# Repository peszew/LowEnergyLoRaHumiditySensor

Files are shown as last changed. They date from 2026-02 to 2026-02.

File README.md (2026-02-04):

# LoRa Wireless Humidity Sensor





> **Bachelor Thesis Project** - A complete IoT solution for wireless environmental monitoring using LoRa communication, featuring a custom-designed PCB with ultra-low power consumption.

**Author:** Piotr Szewczyk  
**University:** Warsaw University of Technology  
**Year:** 2025

---

## Table of Contents

- [Overview](#overview)
- [Features](#features)
- [System Architecture](#system-architecture)
- [Hardware](#hardware)
- [Software](#software)
- [Project Structure](#project-structure)
- [Getting Started](#getting-started)
- [Configuration](#configuration)
- [Power Consumption](#power-consumption)
- [Documentation](#documentation)
- [License](#license)

---

## Overview

This project implements a **wireless humidity and temperature monitoring system** using **LoRa (Long Range)** technology. The system consists of:

1. **Sensor Node** - A battery-powered, custom PCB device that measures environmental conditions and transmits data wirelessly
2. **Gateway/Receiver** - A Raspberry Pi-based receiver that collects data and publishes it to an MQTT broker for integration with home automation systems

The sensor is designed for **ultra-low power consumption**, making it ideal for remote monitoring applications in agriculture, warehouses, smart homes, and industrial environments.

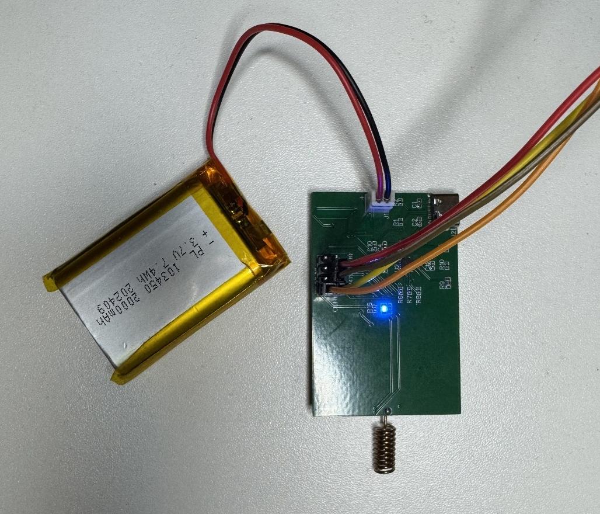
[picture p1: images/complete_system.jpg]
Complete System


---

## Features

| Feature | Description |
|---|---|
| **Temperature Monitoring** | High-precision measurement with HDC1080 sensor (±0.2°C accuracy) |
| **Humidity Monitoring** | Accurate humidity readings (±2% RH accuracy) |
| **Long-Range Communication** | LoRa 868 MHz with RFM95 module (up to several km range) |
| **Battery Monitoring** | Integrated BQ27411 fuel gauge for accurate battery level reporting |
| **Ultra-Low Power** | STM32L0 low-power modes for extended battery life |
| **Smart Alerts** | Automatic alerts for low battery (<20%) or high humidity (>70%) |
| **MQTT Integration** | Seamless integration with home automation systems (Home Assistant, etc.) |
| **Custom PCB Design** | Professionally designed 2-layer PCB with all manufacturing files included |

---

## System Architecture

```
┌─────────────────────────────────────────────────────────────────────────────┐
│                           SENSOR NODE (Battery Powered)                     │
│  ┌──────────────┐   ┌──────────────┐   ┌──────────────┐   ┌──────────────┐  │
│  │   HDC1080    │   │   BQ27411    │   │  STM32L071   │   │    RFM95     │  │
│  │  Temp/Hum    │──▶│  Fuel Gauge  │──▶│     MCU      │──▶│   LoRa TX    │  │
│  │   Sensor     │   │   (I2C)      │   │  (I2C/SPI)   │   │   868 MHz    │  │
│  └──────────────┘   └──────────────┘   └──────────────┘   └──────┬───────┘  │
└──────────────────────────────────────────────────────────────────┼──────────┘
                                                                   │ LoRa
                                                                   ▼
┌─────────────────────────────────────────────────────────────────────────────┐
│                          GATEWAY (Raspberry Pi)                             │
│  ┌──────────────┐   ┌──────────────┐   ┌──────────────┐   ┌──────────────┐  │
│  │    RFM95     │   │   Python     │   │    MQTT      │   │    Home      │  │
│  │   LoRa RX    │──▶│   Receiver   │──▶│   Broker     │──▶│  Automation  │  │
│  │   868 MHz    │   │   Script     │   │ (Mosquitto)  │   │              │  │
│  └──────────────┘   └──────────────┘   └──────────────┘   └──────────────┘  │
└─────────────────────────────────────────────────────────────────────────────┘
```

---

## Hardware

### Assembled PCB

| Sensor Node PCB | With Battery Connected |
|:---:|:---:|
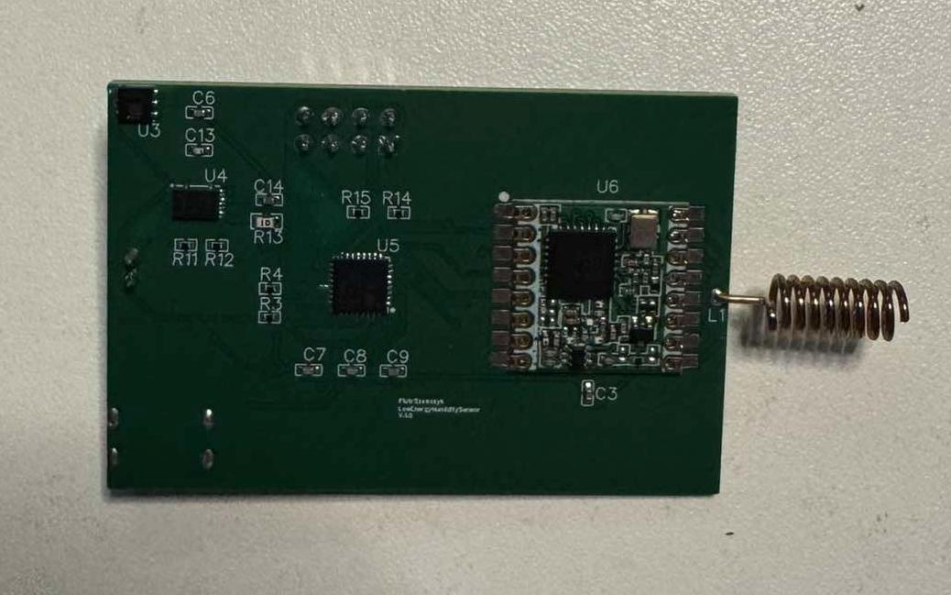
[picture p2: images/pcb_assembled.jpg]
PCB Assembled
|  | Complete System |

### Gateway (Raspberry Pi)

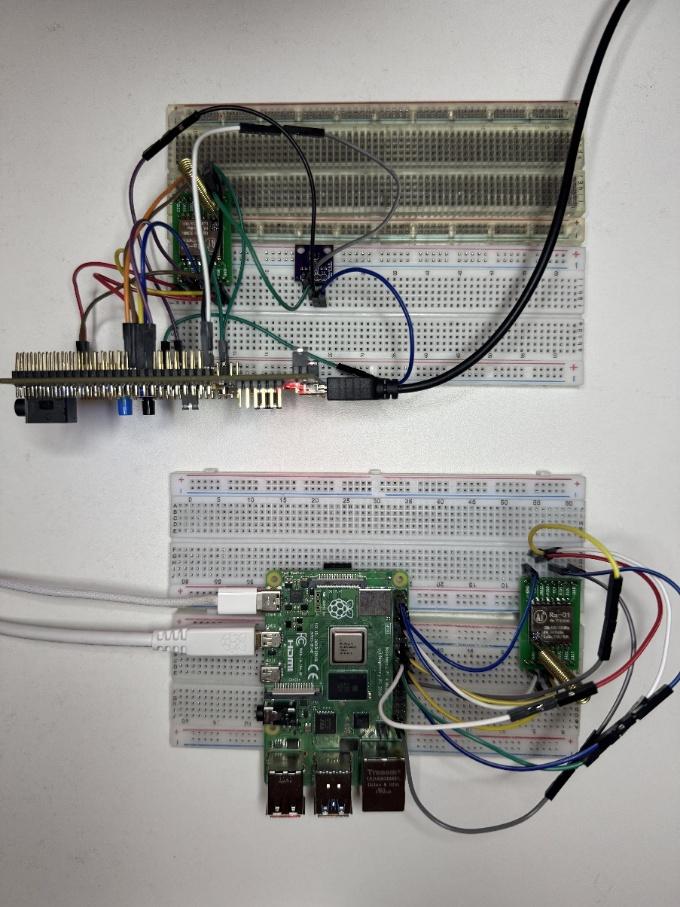
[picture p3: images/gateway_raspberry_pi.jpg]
Raspberry Pi Gateway


### Schematic

The complete schematic includes four main sections:

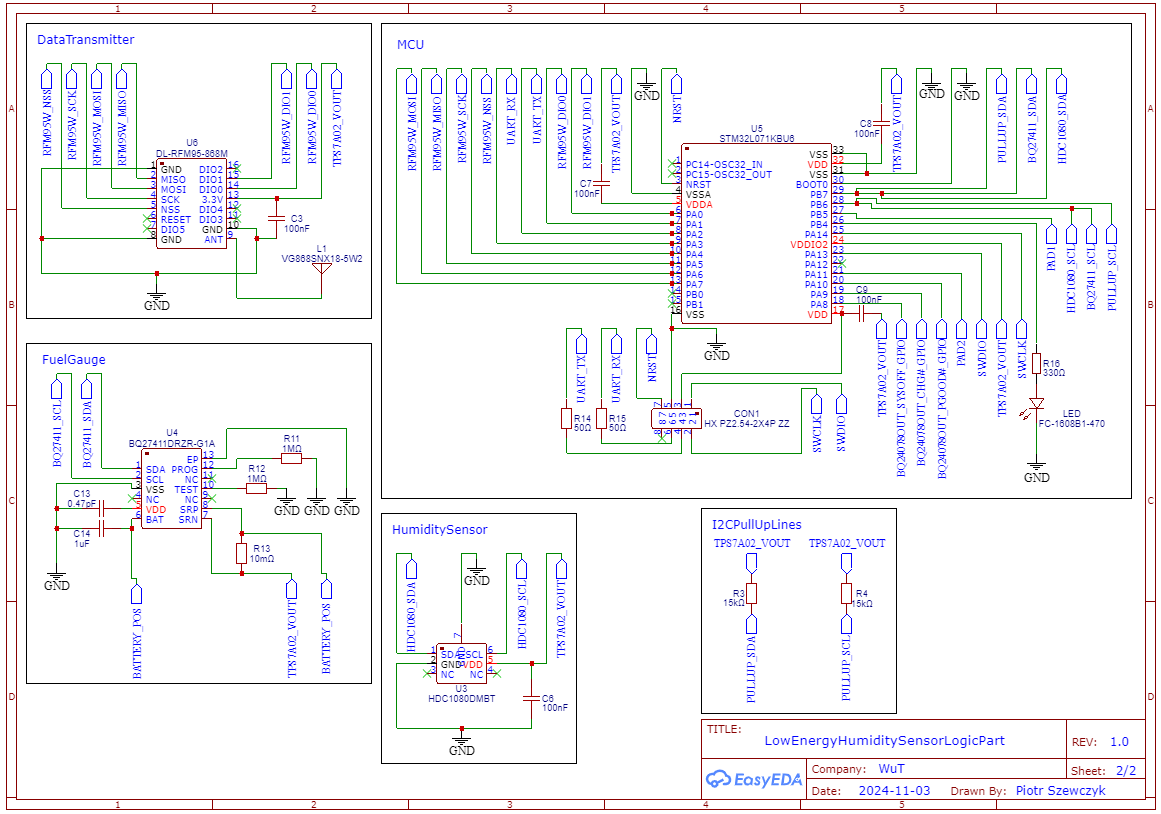
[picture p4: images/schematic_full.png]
Full Schematic


| Power Management | MCU Section |
|:---:|:---:|
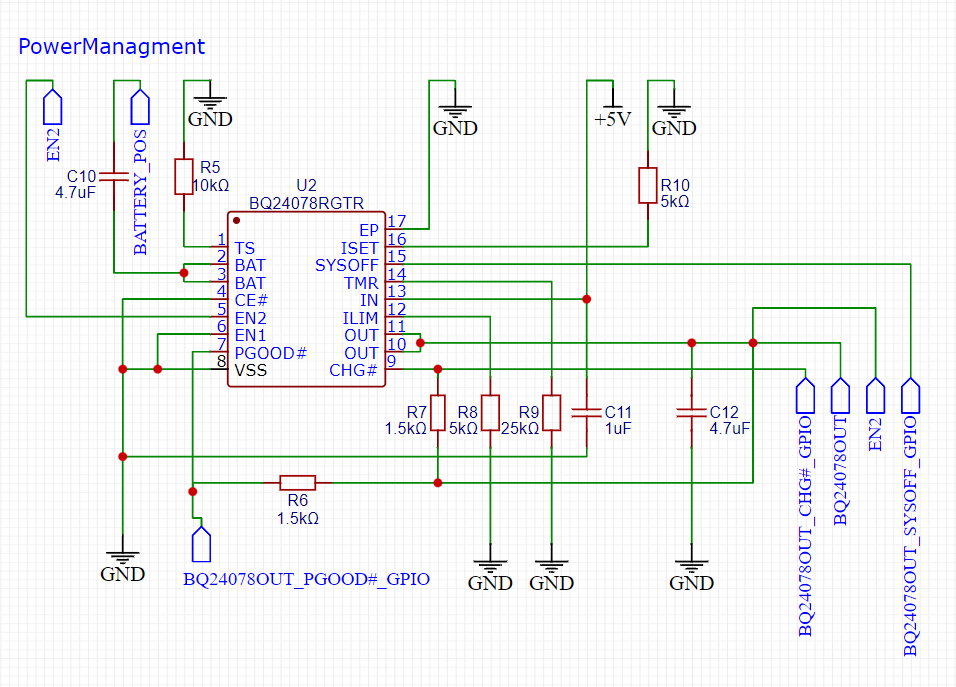
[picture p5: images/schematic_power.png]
Power Schematic
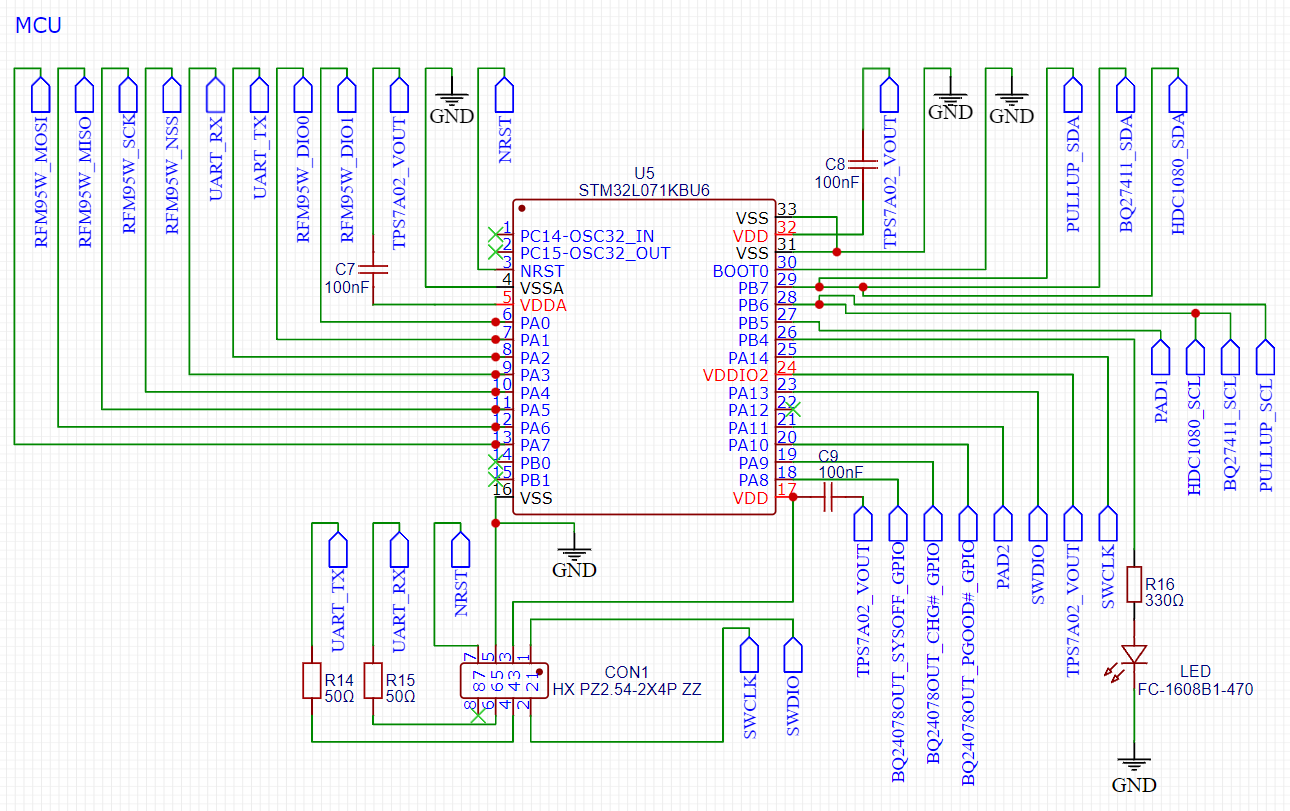
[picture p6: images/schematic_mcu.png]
MCU Schematic
|  |  |

| Fuel Gauge & LoRa | Humidity Sensor |
|:---:|:---:|
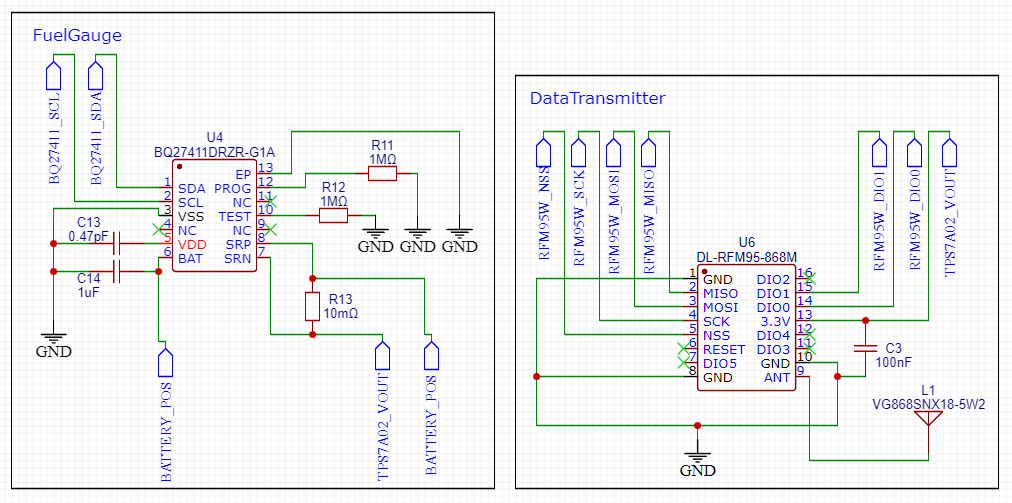
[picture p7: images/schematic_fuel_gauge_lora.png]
Fuel Gauge & LoRa
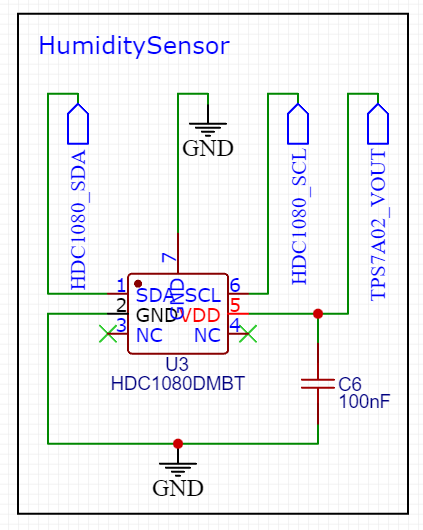
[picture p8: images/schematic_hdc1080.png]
HDC1080 Schematic
|  |  |

### PCB Layout

| Power Section | Main Section |
|:---:|:---:|
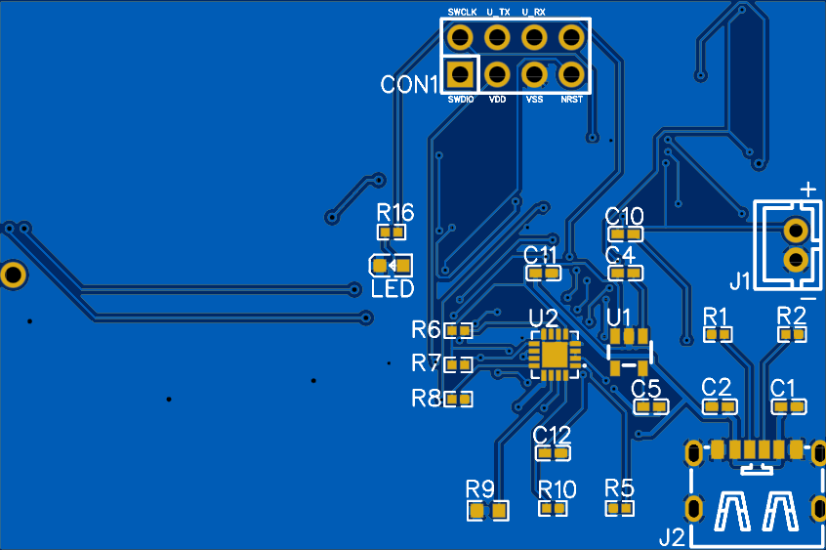
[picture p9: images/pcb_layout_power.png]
PCB Layout Power
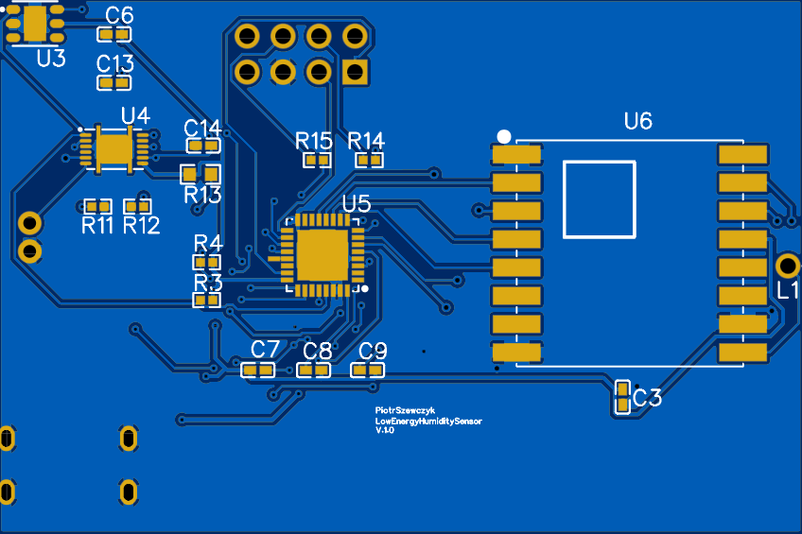
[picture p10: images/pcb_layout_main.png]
PCB Layout Main
|  |  |

### Main Components

| Component | Part Number | Function | Interface |
|---|---|---|---|
| **Microcontroller** | STM32L071KBU6 | Ultra-low-power ARM Cortex-M0+ | - |
| **Humidity/Temperature Sensor** | HDC1080DMBT | Environmental sensing | I2C |
| **LoRa Module** | DL-RFM95-868M | Wireless communication | SPI |
| **Battery Fuel Gauge** | BQ27411DRZR-G1A | Battery level monitoring | I2C |
| **LDO Voltage Regulator** | TPS7A0233PDBVR | 3.3V power supply | - |
| **Battery Charger** | BQ24078RGTR | Li-Ion/Li-Po charging via USB-C | - |
| **Antenna** | VG868SNX18-5W2 | 868 MHz helical antenna | - |

### PCB Details

- **Layers:** 2-layer PCB
- **Dimensions:** Compact design for portable applications
- **Connectors:** 
  - USB Type-C for charging
  - JST PH 2.54mm for battery connection
  - 2x4 pin header for programming/debugging

### Manufacturing Files

The `załączniki/` directory contains all files needed for PCB manufacturing:

- `Gerber_HumSensorV1.0_PCB_HumSensorV1.0_2025-01-28/` - Gerber files for PCB fabrication
- `BOM_HumSensorV1.0_2025-01-28.csv` - Bill of Materials with LCSC part numbers
- `PickAndPlace_PCB_HumSensorV1.0_2025-01-28.csv` - Pick and place file for SMT assembly

---

## Software

### Sensor Node Firmware (STM32)

The firmware is developed using **STM32CubeIDE** and the **STM32 HAL library**.

**Key Features:**
- Ultra-low power operation using STM32 STOP mode
- RTC-based wake-up for periodic measurements
- Averaged humidity readings for stable data
- LoRa transmission with error handling
- Automatic alert generation for critical conditions

**Driver Modules:**

| File | Description |
|---|---|
| `hdc1080.c/.h` | HDC1080 temperature/humidity sensor driver |
| `rfm95.c/.h` | RFM95 LoRa transceiver driver |
| `bq27411.c/.h` | BQ27411 battery fuel gauge driver |
| `main.c` | Main application logic |

### Gateway/Receiver (Python)

The receiver runs on a **Raspberry Pi** and communicates with the sensor via LoRa.

**Features:**
- Continuous LoRa message reception
- Data parsing and validation
- MQTT publishing for home automation integration

**MQTT Topics:**
```
home/lora/temperature  →  Temperature in °C
home/lora/humidity     →  Humidity in %
home/lora/battery      →  Battery level in %
```

---

## Project Structure

```
311105_inz/
├── README.md                          # This file
├── images/                            # Project photos and schematics
│   ├── pcb_assembled.jpg              # Assembled PCB
│   ├── complete_system.jpg            # Complete sensor with battery
│   ├── gateway_raspberry_pi.jpg       # Raspberry Pi gateway
│   ├── schematic_full.png             # Full schematic
│   ├── schematic_mcu.png              # MCU section schematic
│   ├── schematic_power.png            # Power management schematic
│   ├── pcb_layout_main.png            # PCB layout (main)
│   └── pcb_layout_power.png           # PCB layout (power)
├── załączniki/                        # Project attachments
│   ├── 311105_inz.pdf                 # Full thesis documentation (Polish)
│   │
│   ├── HumiditySensor/                # Main firmware project
│   │   └── HumiditySensor/
│   │       ├── Core/
│   │       │   ├── Inc/               # Header files
│   │       │   │   ├── hdc1080.h      # Temperature/humidity sensor
│   │       │   │   ├── rfm95.h        # LoRa transceiver
│   │       │   │   ├── bq27411.h      # Battery fuel gauge
│   │       │   │   └── main.h
│   │       │   └── Src/               # Source files
│   │       │       ├── hdc1080.c
│   │       │       ├── rfm95.c
│   │       │       ├── bq27411.c
│   │       │       └── main.c
│   │       ├── Drivers/               # STM32 HAL drivers
│   │       └── HumiditySensor.ioc     # STM32CubeMX configuration
│   │
│   ├── Gerber_HumSensorV1.0.../       # PCB Gerber files
│   ├── BOM_HumSensorV1.0_2025-01-28.csv        # Bill of Materials
│   ├── PickAndPlace_PCB_HumSensorV1.0_2025-01-28.csv  # SMT assembly file
│   │
│   ├── RFM95_receiver.py              # Full-featured LoRa receiver
│   ├── lora_receiver.py               # Simple LoRa receiver
│   │
│   ├── hdc1080testing.c               # HDC1080 test driver
│   ├── loratesting.c                  # LoRa test driver
│   │
│   ├── testingdht11/                  # DHT11 sensor testing (Arduino)
│   │   └── testingdht11.ino
│   └── testingsyh2r/                  # SYH-2R sensor testing (Arduino)
│       └── testingsyh2r.ino
```

---

## Getting Started

### Prerequisites

**For Sensor Node:**
- STM32CubeIDE (or any ARM GCC toolchain)
- ST-Link programmer/debugger
- USB Type-C cable for charging

**For Raspberry Pi Gateway:**
- Raspberry Pi (any model with SPI support)
- RFM95 LoRa module connected via SPI
- Python 3.x with required packages

### Building the Firmware

1. Clone this repository:
   ```bash
   git clone https://github.com/peszew/LowEnergyLoRaHumiditySensor.git
   ```

2. Open the project in STM32CubeIDE:
   ```
   File → Open Projects from File System → Select załączniki/HumiditySensor/HumiditySensor
   ```

3. Build and flash to the STM32L071:
   ```
   Project → Build All
   Run → Debug
   ```

### Setting Up the Receiver

1. Install Python dependencies:
   ```bash
   pip install spidev paho-mqtt
   ```

2. Enable SPI on Raspberry Pi:
   ```bash
   sudo raspi-config
   # Navigate to: Interfacing Options → SPI → Enable
   ```

3. Run the receiver script:
   ```bash
   python3 RFM95_receiver.py
   ```

---

## Configuration

### LoRa Parameters

| Parameter | Value | Description |
|---|---|---|
| Frequency | 868 MHz | EU ISM band (adjust for your region) |
| Bandwidth | 125 kHz | Standard LoRa bandwidth |
| Spreading Factor | SF7 | Balance between range and speed |
| Coding Rate | 4/5 | Error correction level |

To modify these, edit `rfm95.h`:

```c
#define DEFAULT_FREQUENCY 868000000  // Frequency in Hz
#define DEFAULT_BANDWIDTH 0x72       // 125 kHz
#define DEFAULT_SPREADING_FACTOR 0x74 // SF7
```

### Alert Thresholds

Configured in `main.c`:

```c
if (batteryLevel < 20.0 || humidity > 70.0) {
    // Send alert message
}
```

---

## Power Consumption

The system is optimized for battery operation:

| Mode | Current | Description |
|---|---|---|
| Active (Measuring + Transmitting) | ~50 mA | Brief periods during data transmission |
| STOP Mode (Sleep) | ~2 µA | Most of the operating time |

With a **2000 mAh battery** and measurements every hour, the expected battery life is **several months**.

---

## Documentation

The complete thesis documentation is available in:

**`załączniki/311105_inz.pdf`** (Polish language)

This includes:
- Detailed theoretical background
- System design decisions
- Hardware schematics
- Software implementation details
- Test results and measurements
- Conclusions and future work

---

## License

This project was created as a Bachelor Thesis at **Warsaw University of Technology**.

- The thesis and related materials are the intellectual property of Warsaw University of Technology
- Available for **educational and research purposes only**
- Commercial use requires permission from the author and university

See the [LICENSE](LICENSE) file for details.

---

## Acknowledgments

- STMicroelectronics for the STM32 HAL library
- Texas Instruments for HDC1080 and BQ27411 sensor datasheets
- Semtech for LoRa technology documentation
- Warsaw University of Technology

---

<p align="center">
  <i>Bachelor Thesis Project</i><br>
  <b>Piotr Szewczyk</b><br>
  Warsaw University of Technology, 2025
</p>

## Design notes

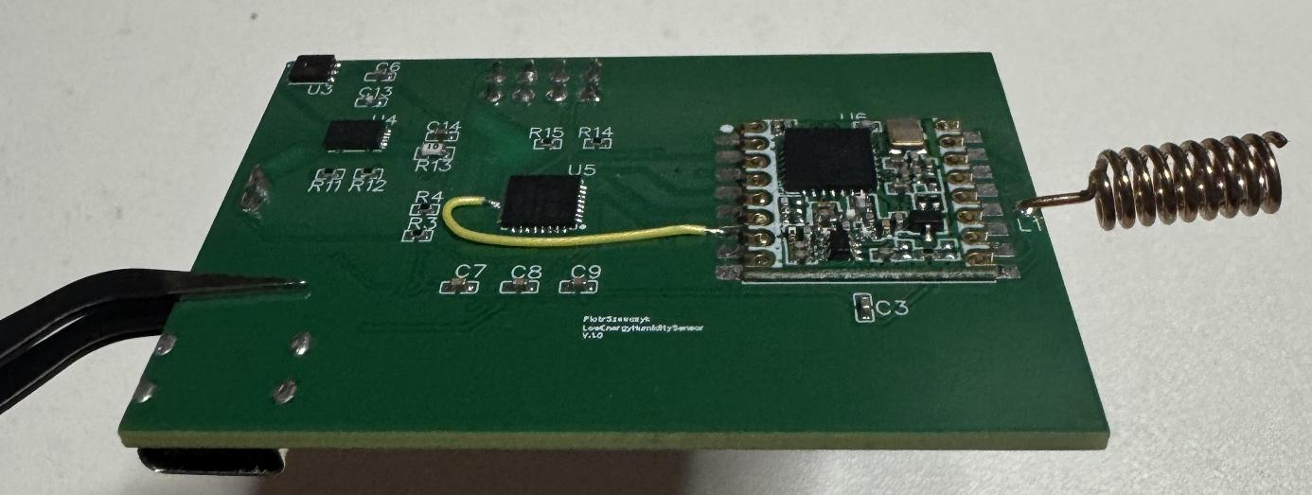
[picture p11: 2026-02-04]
images/pcb_with_wire.jpg

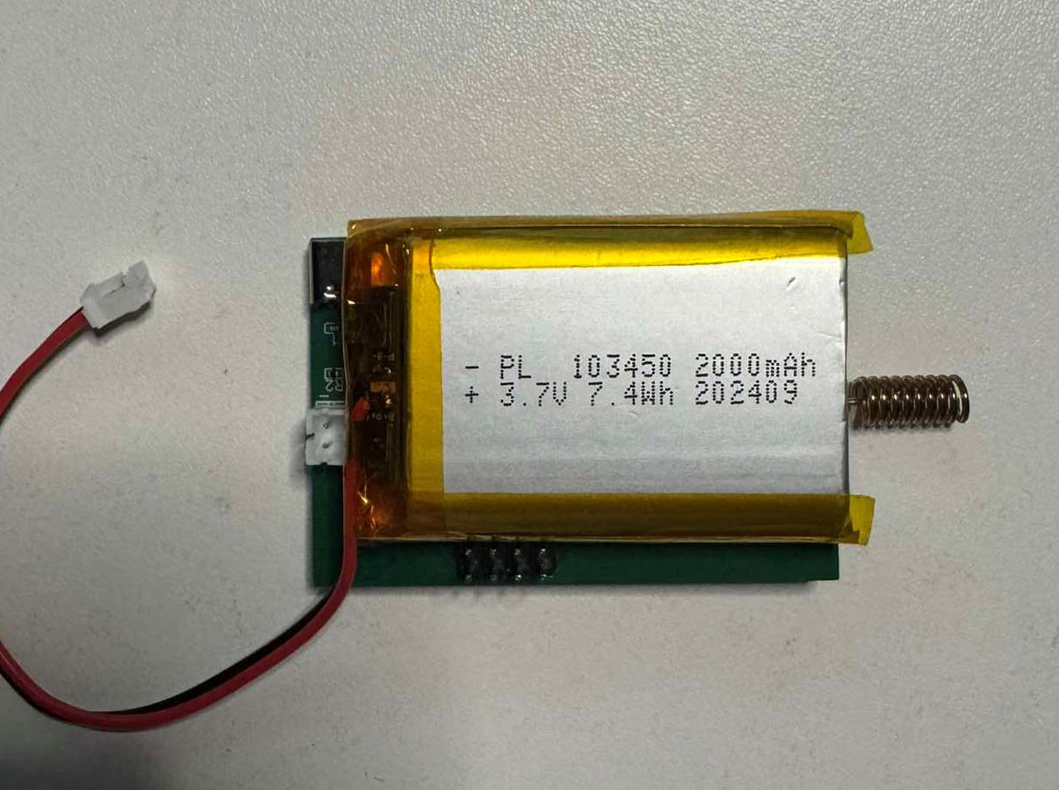
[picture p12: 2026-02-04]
images/battery_module.jpg

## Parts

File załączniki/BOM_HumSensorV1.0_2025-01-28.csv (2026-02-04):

ID | Name | Designator | Footprint | Quantity | Manufacturer Part | Manufacturer | Supplier | Supplier Part | Price
1 | FC-1608B1-470 | LED | LED0603-RD | 1 | FC-1608B1-470 | 国星光电 | LCSC | C19189746 | 0.008
2 | BQ24078RGTR | U2 | VQFN-16_L3.0-W3.0-P0.50-BL-EP | 1 | BQ24078RGTR | TI(德州仪器) | LCSC | C473396 | 1.261
3 | 330Ω | R16 | R0402 | 1 | RC0402JR-07330RL | YAGEO(国巨) | LCSC | C105876 | 0.001
4 | TYPE-C 6P(073) | J2 | TYPE-C-SMD_TYPE-C-6P_5 | 1 | TYPE-C 6P(073) | SHOU HAN(首韩) | LCSC | C668623 | 0.037
5 | TPS7A0233PDBVR | U1 | SOT-23-5_L2.9-W1.6-P0.95-LS2.8-BR | 1 | TPS7A0233PDBVR | TI(德州仪器) | LCSC | C2887324 | 0.648
6 | B2B-PH-K-S(LF)(SN) | J1 | CONN-TH_B2B-PH-K-S | 1 | B2B-PH-K-S(LF)(SN) | JST | LCSC | C131337 | 0.033
7 | 100nF | C1,C2,C3,C6,C7,C8,C9 | C0402 | 7 | TCC0402X7R104K500AT | CCTC(三环) | LCSC | C5448791 | 0.002
8 | 1uF | C4,C5,C11,C14 | C0402 | 4 | HGC0402S6105K250NTEJ | Chinocera(华瓷) | LCSC | C7472947 | 0.009
9 | 4.7uF | C10,C12 | C0402 | 2 | CL05A475MO5NUNC | SAMSUNG(三星) | LCSC | C318563 | 0.013
10 | 5.1kΩ | R1,R2 | R0402 | 2 | ERA2AEB512X | PANASONIC(松下) | LCSC | C490833 | 0.088
11 | 10kΩ | R5 | R0402 | 1 | RT0402FRE0710KL | YAGEO(国巨) | LCSC | C723366 | 0.011
12 | 1.5kΩ | R6,R7 | R0402 | 2 | AC0402JR-071K5L | YAGEO(国巨) | LCSC | C144726 | 0.001
13 | 5kΩ | R8,R10 | R0402 | 2 | RC0402FR-075KL | YAGEO(国巨) | LCSC | C477765 | 0.001
14 | 25kΩ | R9 | R0603 | 1 | AR03BTCX2502 | Viking(光颉) | LCSC | C2828637 | 0.032
15 | HX PZ2.54-2X4P ZZ | CON1 | HDR-TH_8P-P2.54-V-M-R2-C4-S2.54 | 1 | HX PZ2.54-2x4P ZZ | hanxia(韩下) | LCSC | C32713277 | 0.029
16 | VG868SNX18-5W2 | L1 | ANT-TH_VG868SNX18-5W2 | 1 | VG868SNX18-5W2 | Vollgo(沃进) | LCSC | C718843 | 0.189
17 | 0.47pF | C13 | C0402 | 1 | CC0402BRNPO9BNR47 | YAGEO(国巨) | LCSC | C114389 | 0.002
18 | BQ27411DRZR-G1A | U4 | SON-12_L4.0-W2.5-P0.40-TL-EP | 1 | BQ27411DRZR-G1A | TI(德州仪器) | LCSC | C2878138 | 2.36
19 | HDC1080DMBT | U3 | WSON-6_L3.0-W3.0-P0.95-TL-EP | 1 | HDC1080DMBT | TI(德州仪器) | LCSC | C2864159 | 0.631
20 | STM32L071KBU6 | U5 | UFQFPN-32_L5.0-W5.0-P0.50-BL-EP3.5 | 1 | STM32L071KBU6 | ST(意法半导体) | LCSC | C911078 | 3.08
21 | 15kΩ | R3,R4 | R0402 | 2 | RC0402FR-075KL | YAGEO(国巨) | LCSC | C477765 | 0.001
22 | 1MΩ | R11,R12 | R0402 | 2 | ERJPA2J105X | PANASONIC(松下) | LCSC | C427228 | 0.035
23 | 50Ω | R14,R15 | R0402 | 2 | RC0402JR-0750RL | YAGEO(国巨) | LCSC | C477760 | 0.001
24 | 10mΩ | R13 | R0603 | 1 | CSRF0603FT10L0 | SEI(Stackpole Electronics Inc.) | LCSC | C346485 | 0.258
25 | DL-RFM95-868M | U6 | COMM-SMD_RFM95W | 1 | DL-RFM95-868M | DreamLNK(骏晔科技) | LCSC | C2844472 | 7.067

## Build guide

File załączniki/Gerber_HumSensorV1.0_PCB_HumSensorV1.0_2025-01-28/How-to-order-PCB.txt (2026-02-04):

How to Order PCB

Please refer to:
https://docs.easyeda.com/en/PCB/Order-PCB

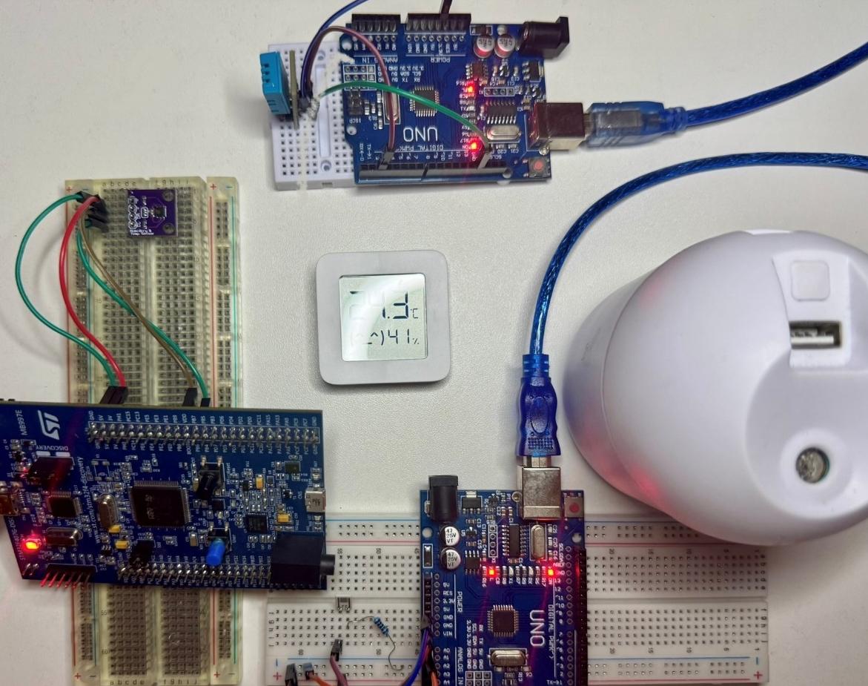
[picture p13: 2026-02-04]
images/development_setup.jpg

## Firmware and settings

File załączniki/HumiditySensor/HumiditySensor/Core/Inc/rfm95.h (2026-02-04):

#ifndef RFM95_H
#define RFM95_H

#include "stm32l0xx_hal.h"

// RFM95 Registers
#define REG_OP_MODE 0x01
#define MODE_SLEEP 0x00
#define MODE_STDBY 0x01
#define MODE_TX 0x03
#define REG_FRF_MSB 0x06
#define REG_FRF_MID 0x07
#define REG_FRF_LSB 0x08
#define REG_FIFO 0x00
#define REG_PAYLOAD_LENGTH 0x22
#define REG_IRQ_FLAGS 0x12
#define REG_MODEM_CONFIG1 0x1D
#define REG_MODEM_CONFIG2 0x1E


#define DEFAULT_FREQUENCY 868000000 //
#define DEFAULT_BANDWIDTH 0x72 // 125 kHz
#define DEFAULT_CODING_RATE 0x04 // 4/5
#define DEFAULT_SPREADING_FACTOR 0x74 // SF7
#define DEFAULT_CRC 0x04 // CRC
#define TX_TIMEOUT 3000 // Timeout

void RFM95_Init(SPI_HandleTypeDef *hspi, GPIO_TypeDef *nssPort, uint16_t nssPin, GPIO_TypeDef *dio0Port, uint16_t dio0Pin);
void RFM95_EnterSleepMode(void);
void RFM95_EnterStandbyMode(void);
void RFM95_SetPayloadLength(uint8_t length);
void RFM95_SendMessage(const char *message);
void RFM95_HandleError(void);


#endif

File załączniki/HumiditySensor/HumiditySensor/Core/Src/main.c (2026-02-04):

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
/* Includes ------------------------------------------------------------------*/
#include "main.h"

/* USER CODE BEGIN Includes */
#include "hdc1080.h"
#include "bq27411.h"
#include "rfm95.h"
#include <stdio.h>
#include <string.h>
/* USER CODE END Includes */

I2C_HandleTypeDef hi2c1;

RTC_HandleTypeDef hrtc;

SPI_HandleTypeDef hspi1;

void SystemClock_Config(void);
static void MX_GPIO_Init(void);
static void MX_I2C1_Init(void);
static void MX_RTC_Init(void);
static void MX_SPI1_Init(void);
/* USER CODE BEGIN 0 */
void HAL_RTC_AlarmAEventCallback(RTC_HandleTypeDef *hrtc) {
}

/* USER CODE END 0 */

/**
  * @brief  The application entry point.
  * @retval int
  */
int main(void)
{

  /* MCU Configuration--------------------------------------------------------*/

  /* Reset of all peripherals, Initializes the Flash interface and the Systick. */
  HAL_Init();

  /* Configure the system clock */
  SystemClock_Config();

  /* Initialize all configured peripherals */
  MX_GPIO_Init();
  MX_I2C1_Init();
  MX_RTC_Init();
  MX_SPI1_Init();
  /* USER CODE BEGIN 2 */
  HDC1080_Init(&hi2c1);
  bq27411_Init(&hi2c1);
  RFM95_Init(&hspi1, GPIOA, GPIO_PIN_4, GPIOA, GPIO_PIN_1);


  RTC_TimeTypeDef currentTime;
  RTC_DateTypeDef currentDate;
  /* USER CODE END 2 */

  /* Infinite loop */
  /* USER CODE BEGIN WHILE */
  while (1)
  {
	  HAL_PWR_EnterSTOPMode(PWR_LOWPOWERREGULATOR_ON, PWR_STOPENTRY_WFI);

	         HAL_RTC_GetTime(&hrtc, &currentTime, RTC_FORMAT_BIN);
	         HAL_RTC_GetDate(&hrtc, &currentDate, RTC_FORMAT_BIN);

	         currentTime.Hours = 17;
	         currentTime.Minutes = 0;
	         currentTime.Seconds = 0;

	         float temperature = HDC1080_ReadTemperature();
	         float humidity = HDC1080_AverageHumidity();
	         float batteryLevel = bq27411_GetStableBatteryLevel();

	         if (batteryLevel < 20.0 || humidity > 70.0) {
	             char alertMessage[32];
	             snprintf(alertMessage, sizeof(alertMessage), "T:%.1f, H:%.1f, B:%.0f", temperature, humidity, batteryLevel);
	             RFM95_SendMessage(alertMessage);
	         }

	         if (currentDate.Date == 1) {
	             char monthlyReport[32];
	             snprintf(monthlyReport, sizeof(monthlyReport), "T:%.1f, H:%.1f, B:%.0f", temperature, humidity, batteryLevel);
	             RFM95_SendMessage(monthlyReport);
	         }

	         RFM95_EnterSleepMode();

    /* USER CODE END WHILE */

    /* USER CODE BEGIN 3 */
  }
  /* USER CODE END 3 */
}

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


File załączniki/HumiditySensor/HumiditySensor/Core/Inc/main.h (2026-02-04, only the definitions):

#define DIO1_Pin GPIO_PIN_0
#define DIO1_GPIO_Port GPIOA
#define DIO1_EXTI_IRQn EXTI0_1_IRQn
#define DIO0_Pin GPIO_PIN_1
#define DIO0_GPIO_Port GPIOA
#define DIO0_EXTI_IRQn EXTI0_1_IRQn
#define NSS_Pin GPIO_PIN_4
#define NSS_GPIO_Port GPIOA

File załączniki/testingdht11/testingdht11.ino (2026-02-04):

#include <dht.h>

// Define the pin where the DHT11 is connected
#define DHTPIN 2  // Digital pin 2

dht DHT; // Create an instance of the dht class

void setup() {
  Serial.begin(9600);
  Serial.println("DHT11 Sensor Reading");
}

void loop() {
  // Read data from the DHT11 sensor
  DHT.read11(DHTPIN);

  // Print temperature and humidity readings
  Serial.print("Humidity: ");
  Serial.print(DHT.humidity, 1); // Humidity value with 1 decimal point
  Serial.print(" %\t");
  Serial.print("Temperature: ");
  Serial.print(DHT.temperature, 1); // Temperature value with 1 decimal point
  Serial.println(" °C");

  // Wait 2 seconds before taking another reading
  delay(2000);
}

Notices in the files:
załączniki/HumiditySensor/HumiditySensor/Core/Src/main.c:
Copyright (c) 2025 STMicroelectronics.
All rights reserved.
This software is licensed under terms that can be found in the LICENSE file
